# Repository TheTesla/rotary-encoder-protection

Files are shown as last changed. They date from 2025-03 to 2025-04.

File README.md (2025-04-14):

# Rotary Encoder Protection Board

The rotary encoders don't have any electrical protection mechanism. Overcurrent into the open collector outputs will damage them.

This board protects the rotary encoder against reverse polarity and short overvoltage spikes on the power supply line. Each data line is protected using a 10k resistor in series. Pull-up resistors are incooperated on the encoder side. That means, the board outputs are directly high impedance logic level. External voltage to these data pins won't damage the encoder or protection board.

Direct connection to ICs with a low voltage tolerance at the inputs is possible, because the clamp diodes in the IC will limit the voltage from the high impedance outputs of the board. 

## Associated Projects

That protection board is part of the plug at the rotary encoder cable. It is intended to be connected to the logic board, which implements the data processing:

* https://github.com/TheTesla/OSH-CMM-LogicBoard

## Author/Contact

Stefan Helmert <stefan.helmert@htw-dresden.de>

## Appendix

### Pictures

The PCB without case and without rotary encoder:

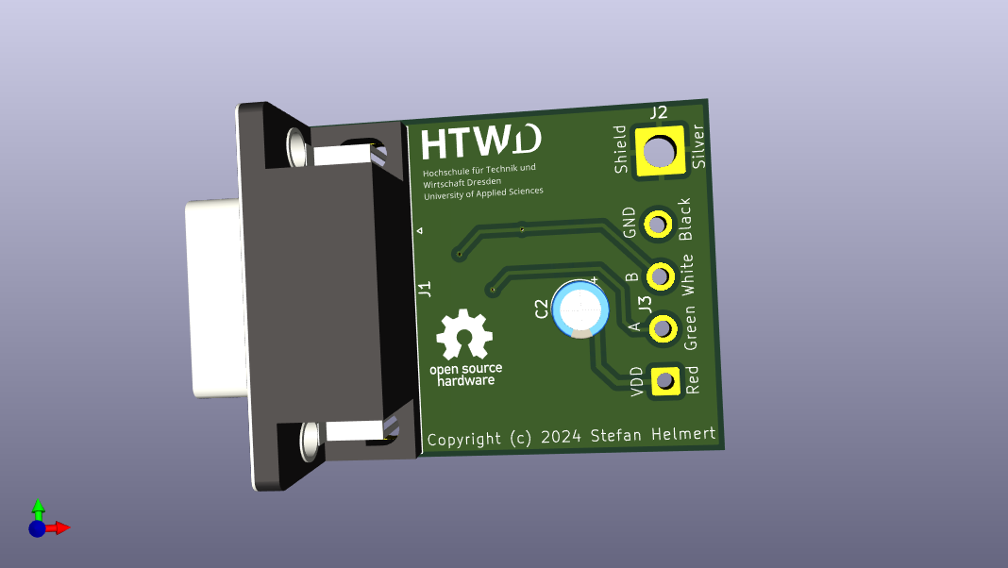
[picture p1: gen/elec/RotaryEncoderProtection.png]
3d rendered image of the assembled pcb, front


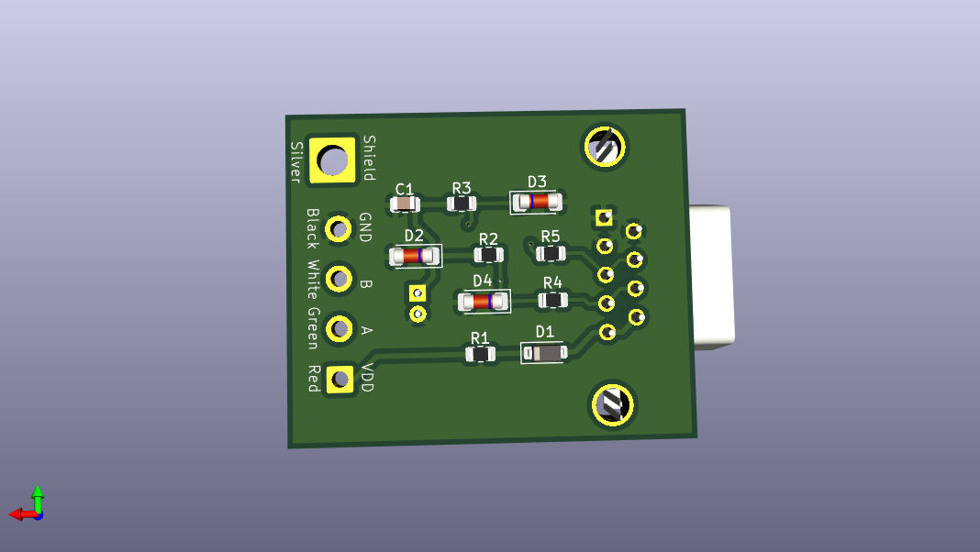
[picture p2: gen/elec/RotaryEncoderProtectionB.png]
3d rendered image of the assembled pcb, back


### Schematics

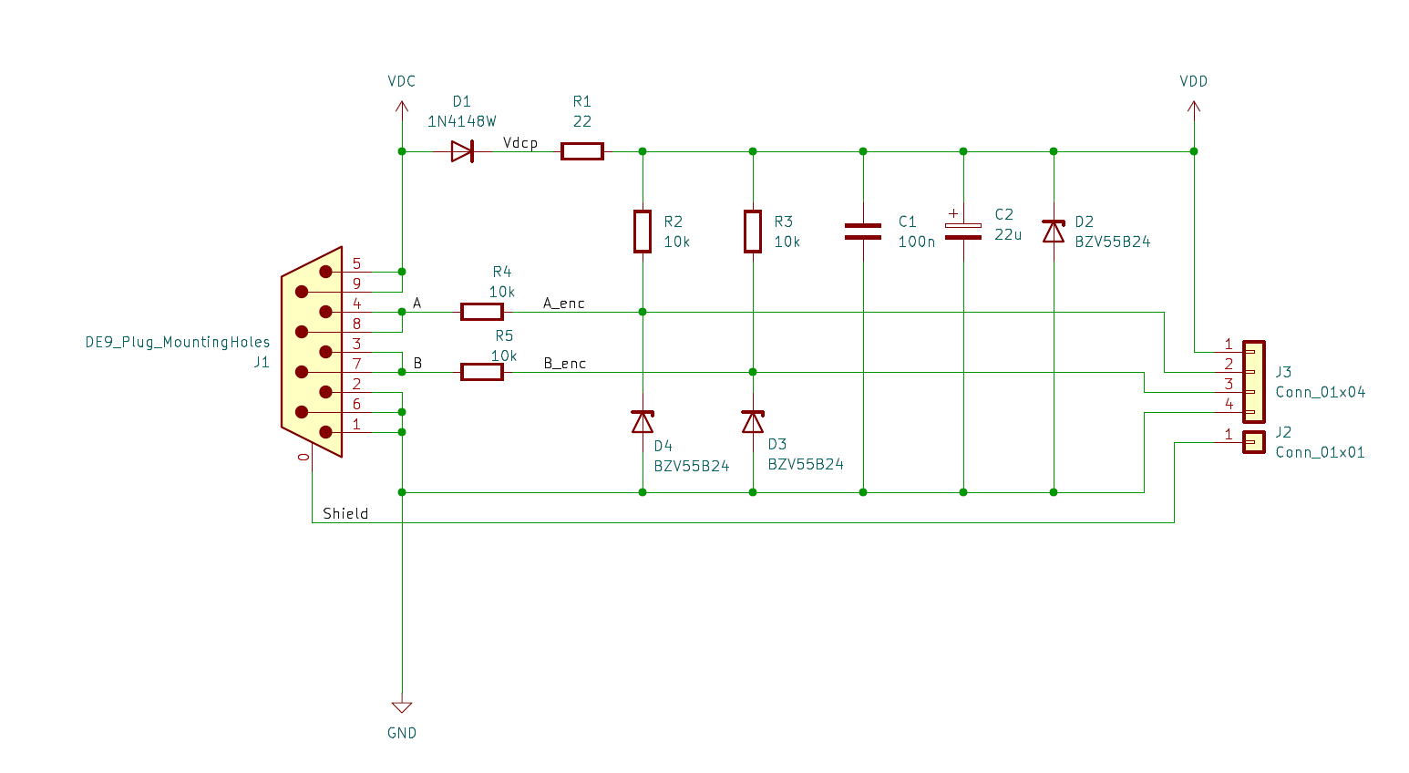
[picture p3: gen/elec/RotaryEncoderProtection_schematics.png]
schematics


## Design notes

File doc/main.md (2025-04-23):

# How it works

This electrical component protects the optical rotary encoder against overvoltage, short circuit and wrong polarity. That means, any voltage up to 25 V randomly applied to any of the four electrical connections is completely safe and will never do any damage to the board or the encoder.

The protection mechanisms are implemented the following way:

## Supply voltage protection

The optical rotary encoder can be operated by 5 to 24 V consuming up to 40 mA. Diode _D1_ protects it against reverse supply voltage polarity by up to 100 V.

During normal operation, there is a voltage drop 0f arount 0.7 V over _D1_ and 0.9 V over _R1_. The rotary encoders gets around 1.6 V less than the voltage supplied into the protection board. The over voltage protection is mainly realized by the z-diode _D2_. In an over voltage condition, it starts to conduct current, rising the input current to the protection board. The protection works for voltage surges of up to 50 V for 100 us. In this situation, the current is around 1.1 A.

The low impedance capacitors _C1_ protects against radio frequency inference on the power rail, while _C2_ protects against lower frequencies. It protects the encoder against power interruptions of around 1 ms, which would lead to minor errors in counting the angle value. The cutoff frequency of the RC filter _R1_ and _C2_ is around 330 Hz.

## Signal output protection

The rotary encoder has two open collector outputs. They don't have any internal current limitation or protection. To limit the current, the resistors _R4_ and _R5_ are added in series. Because this method increases te output impedance, the pull-up resistors are added to the encoder side. This way, the voltage level of the signal is not impaired. It is important to disable integrated pull-up resistors in the microcontroller, where the protection board ist plugged in, because due to the high output impedance of 10 kOhm, the voltage level can't be pulled low enough from the protection board side.

The high output impedance also protects the connected (microcontroller) circuit. If the digital port of the microcontroller (Arduino) is programmed as output, e. g. the wrong program ist loaded or there is a bug in the code, current flowing through the digital port is limited to a safe value. Because the output impedance is 20 kOhm for high level, the output current can't reach more than 1.2 mA, if the output is shorted to _GND_. If the supply voltage is 24 V and a microcnotrller is directly connected to this output, it won't be damaged, because the internal protection diodes of the microcontroller limit the voltage level on the input port.

If over voltage is feed directly into the output port, the z-diodes _D3_ and _D4_ protect the encoder outputs against over voltage, if they are on high level. In case of reverse polarity over voltage at the output ports, there is a forward current flow through both z-diodes, which protects the encoder output against negative voltage levels.

## Connection check 

There is always a probability a plug comes loose or there is an internal problem in the mainboard. The protection board allows to check the connection to it. Even both output pins of the rotary encoder are high, which means, the open collector ouput pins are in the high impedance state, the signal connection can be checked, because there is a 20 kOhm path through the protection and pull-up resistors to the positive supply voltage. If the output level of the encoder is low, the output impedance of the board is 10 kOhm to _GND_.

The optical rotary encoder always draws supply current, if the supply voltage is in the recommended range. That way, the supply voltage or _GND_ connection can be checked.

# Important notes

Only the _J1_ sub-d connector side is protected! The open end of the cable of the rotary encoder must be soldered directly to the protection board. Because the protection board serves also as a plug, no detachable connection should be introduced between the encoder and the board. If a longer cable is needed, it should be attached to the protected _J1_ connector side. Feeding reverse polarized or over voltage to the _J3_ solder pads, where regularly the encoder cable is soldered to, will damage the protection board and destroy the protection functionality.

Applying more than 25 V over a long time directly to the output or supply connection can cause overheat and fire.

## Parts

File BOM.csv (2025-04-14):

Reference | Value | Datasheet | Footprint | Qty | DNP | Reichelt.de
C1 | 100n | ~ | Capacitor_SMD:C_0805_2012Metric | 1 |  | X7R-G0805 100N
C2 | 22u | ~ | Capacitor_THT:CP_Radial_D5.0mm_P2.00mm | 1 |  | RAD 22/35
D1 | 1N4148W | https://www.vishay.com/docs/85748/1n4148w.pdf | Diode_SMD:D_SOD-123 | 1 |  | 1N 4148W DIO
D2,D3,D4 | BZV55B24 | https://assets.nexperia.com/documents/data-sheet/BZV55_SER.pdf | Diode_SMD:D_MiniMELF | 3 |  | SMD ZF 24
J1 | DE9_Plug_MountingHoles | https://cdn-reichelt.de/documents/datenblatt/C120/DBR1-MXX-L.pdf | Connector_Dsub:DSUB-9_Male_Horizontal_P2.77x2.84mm_EdgePinOffset4.94mm_Housed_MountingHolesOffset7.48mm | 1 |  | D-SUB ST 09US
J2 | Conn_01x01 | ~ | Connector_Wire:SolderWire-2.5sqmm_1x01_D2.4mm_OD4.4mm | 1
J3 | Conn_01x04 | ~ | Connector_Wire:SolderWire-0.75sqmm_1x04_P4.8mm_D1.25mm_OD2.3mm | 1
R1 | 22 | ~ | Resistor_SMD:R_0805_2012Metric | 1 |  | SMD-0805 22,0
R2,R3,R4,R5 | 10k | ~ | Resistor_SMD:R_0805_2012Metric | 4 |  | SMD-0805 10,0K

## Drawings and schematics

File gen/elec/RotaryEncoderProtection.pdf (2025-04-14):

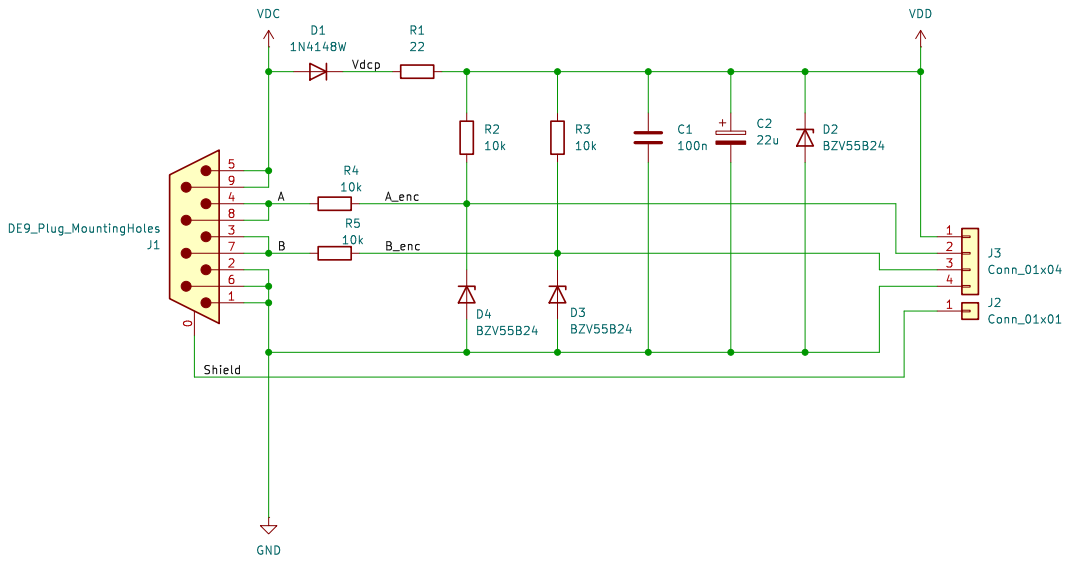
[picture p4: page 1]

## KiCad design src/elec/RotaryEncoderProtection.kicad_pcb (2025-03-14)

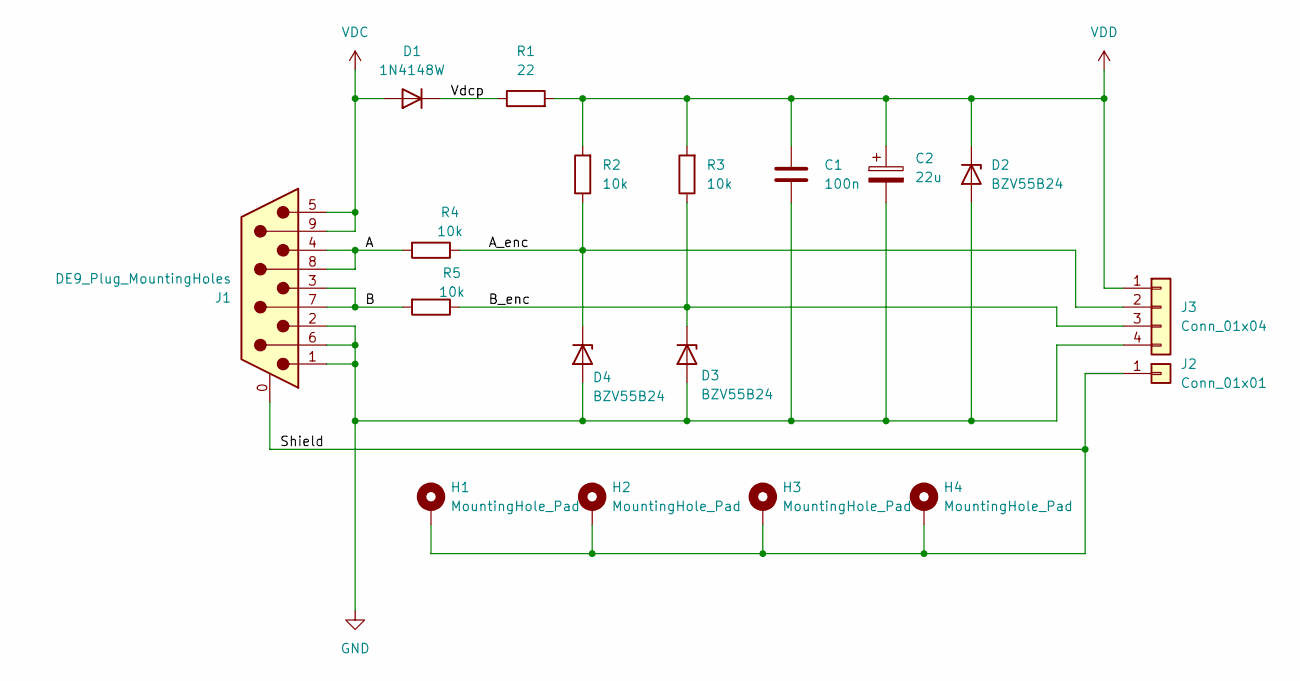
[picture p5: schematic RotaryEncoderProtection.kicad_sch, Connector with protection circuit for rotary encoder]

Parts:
C1: 100n; C_0805_2012Metric
C2: 22u; CP_Radial_D5.0mm_P2.00mm
D1: 1N4148W; D_SOD-123
D2, D3, D4: BZV55B24; D_MiniMELF
H1, H2, H3, H4: MountingHole_Pad; MountingHole_2.7mm_M2.5_ISO14580_Pad_TopBottom
J1: DE9_Plug_MountingHoles; DSUB-9_Pins_Horizontal_P2.77x2.84mm_EdgePinOffset7.70mm_Hou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
J2: Conn_01x01; SolderWire-2.5sqmm_1x01_D2.4mm_OD4.4mm
J3: Conn_01x04; SolderWire-0.75sqmm_1x04_P4.8mm_D1.25mm_OD2.3mm
R1: 22; R_0805_2012Metric
R2, R3, R4, R5: 10k; R_0805_2012Metric

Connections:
/A: J1.4, J1.8, R4.2
/A_enc: D4.1 (K), J3.2, R2.1, R4.1
/B: J1.3, J1.7, R5.2
/B_enc: D3.1 (K), J3.3, R3.1, R5.1
/Shield: H1.1, H2.1, H3.1, H4.1, J1.0 (PAD), J2.1
/Vdcp: D1.1 (K), R1.1
GND: C1.2, C2.2, D2.2 (A), D3.2 (A), D4.2 (A), J1.1, J1.2, J1.6, J3.4
VDC: D1.2 (A), J1.5, J1.9
VDD: C1.1, C2.1, D2.1 (K), J3.1, R1.2, R2.2, R3.2

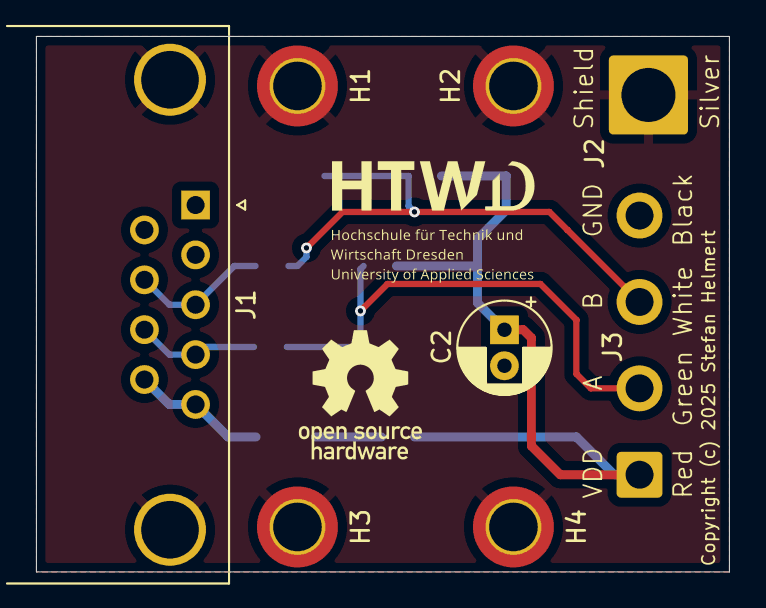
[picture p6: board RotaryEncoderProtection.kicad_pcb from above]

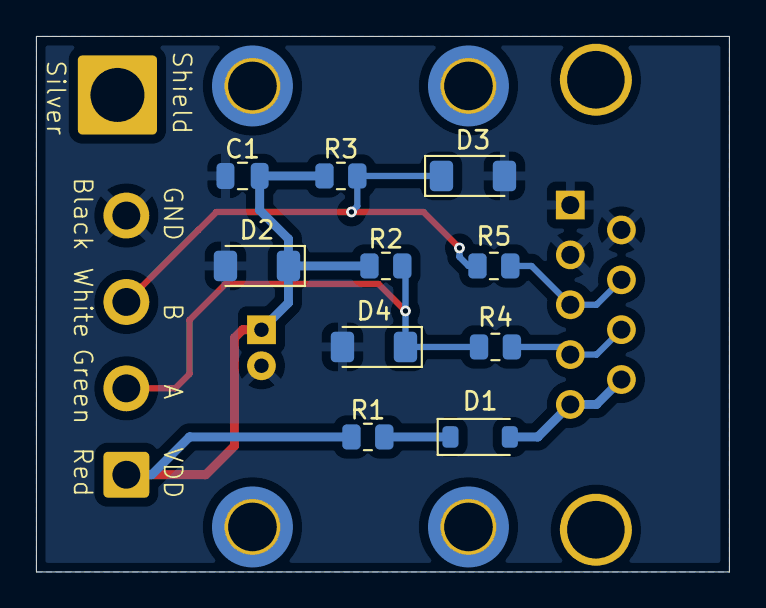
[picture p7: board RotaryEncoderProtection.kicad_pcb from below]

Board: 2 copper layers, 38.5 x 29.8 mm, 18 parts (10 on the bottom side), 9 nets.

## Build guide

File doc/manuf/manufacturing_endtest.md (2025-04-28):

# Manufacturing Endtest

After the production process all electrical functions should be tested. This test procedure is designed to fully test all electrical functions, even if all parts including the rotary encoder are soldered and only the sub-d port electrical connection is accessible, because the case is already closed.

## Test Setup

The sub-d connector is connected to the test equipment. The rotary encoder is mounted in the test stand, which rotates the shaft.

## Normal Operation

The operation voltage of 9 V DC is applied. The current must be limited to 50 mA.

### Power Supply

The current limit must not be reached.

### Output Signals

- The output voltage level must be >5 V for high level and <1.5 V for low level.

- The output waveform must show the quadrature signal waveform according the reference setup.

- An AC output impedance test during normal operation must show an impedance of 10 kOhm (+-20%) during low level and 20 kOhm (+-20%) during high level.

## Protection Functions

This section describes the test conditions for different protection functions.

### Power Supply

#### Reverse Polarity

The following procedure checks diode _D1_.

50 V DC should be applied in reverse direction to the power supply rails. The current must be limited to 100 uA. The current limit must not be reached.

#### Over Voltage

This procedure checks z-diode _D2_.

Apply 50 V DC, limited to 100 mA for 30 ms with correct polarity. The current limit must be maintained until the end of the pulse. The voltage level must not be higher than 30 V.

### Output Signals

The following procedure checks the z-diodes _D3_ (signal _B_) and _D4_ (signal _A_). 

Apply 24 V supply voltage with 50 mA current limit. While the rotary encoder outputs high level on both data lines:

- Apply -5 V with 10 mA current limit to the signal outputs. Measure the dynamic impedance. It must be 10 kOhm (+-20%).

- Apply +50 V with 5 mA current limit to the signal outputs. Measure the dynamic impedance. It must be 10 kOhm (+-20%).

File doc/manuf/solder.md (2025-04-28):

# Recommended steps

1. place and solder all SMD compoents
2. place and solder THT components
3. solder rotary encoder cable according the colors written on the PCB

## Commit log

2024-07-05 removed traces, where zones are; added text, logos, copyright; added Reichelt article numbvers
    [RotaryEncoderProtection.kicad_pcb, RotaryEncoderProtection.kicad_sch]
2024-07-19 optimized silkscreen
    [RotaryEncoderProtection.kicad_pcb]
2024-07-29 smaller board
    [RotaryEncoderProtection.kicad_pcb, RotaryEncoderProtection.kicad_sch]
2024-09-11 case for protaction board nearly ready
    [CasePlug.FCStd]
2024-09-12 one part of case ready
    [CasePlug.FCStd]
2024-09-13 added fillet
    [CasePlug.FCStd]
2024-11-22 construction of case for the plug is ready but not tested yet
    [CasePlug-Cut009.step, CasePlug-Fillet002.step, CasePlug.FCStd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]
2024-11-27 xyzcad version of case top
2024-11-27 case top looks ready
2024-11-27 more resolution; added artefact (stl)
2024-11-27 bottom case nearly ready
2024-11-27 added Freecad file to compare case to PCB; bottom case nearly ready
    [PlugCaseTest.FCStd]
2024-11-27 case with rounder outer edges, fits better, single file
2025-03-14 Digikey M3 D-Sub-9 Connector
    [CasePlug.FCStd, RotaryEncoderProtection.kicad_pcb, RotaryEncoderProtection.kicad_sch]
2025-03-14 new KiCad Standard D-Sub-9 Connector
    [RotaryEncoderProtection.kicad_pcb, RotaryEncoderProtection.kicad_sch]
2025-03-14 replaced Reichelt SKU for D-Sub-9 Connector
    [RotaryEncoderProtection.kicad_sch]
2025-04-14 OSH documentation guideline structure
    [BOM.csv, CasePlug-Cut009.step, CasePlug-Fillet002.step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]
2025-04-28 added soldering and testing instractions; ToDo: testing instructions for protection of data pins

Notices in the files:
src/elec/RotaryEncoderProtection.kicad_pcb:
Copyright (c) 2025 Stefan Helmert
